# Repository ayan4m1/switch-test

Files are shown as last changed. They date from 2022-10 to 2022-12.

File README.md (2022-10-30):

# SwitchTest

An open-source mechanical keyswitch tester.

## Purpose

To provide a simple, reliable, and fast way to test a batch of keyswitches. You might want to perform batch testing after opening the switch housings in order to lubricate or swap springs. It can also be useful for those who buy and sell keyswitches, to quickly check them after receipt or before shipping.

## Bill of Materials

| Qty | Part | Notes |
| --- | --- | --- |
| 1 | [10k Ohm Resistor](https://www.amazon.com/dp/B072BL2VX1) | Through-hole, 1/4W is sufficient |
| 1 | [PS1240P02CT3](https://www.mouser.com/ProductDetail/810-PS1240P02CT3) | Piezo buzzer, 4kHz |
| 1 | [QT Py ESP32-S3](https://www.adafruit.com/product/5426) | |
| 1 | [0.96" SSD1306 OLED](https://www.amazon.com/gp/product/B0837DLWVH) | |
| 1 | [Kailh hotswap socket](https://divinikey.com/products/kailh-hot-swap-sockets) | |
| 4 | [M3 Standoffs](https://www.amazon.com/dp/B098XS4C3D) | 8-15mm length |
| 8 | M3 Screws | 5mm length |

You will also need a 3D printed [baseplate](./hardware/baseplate.stl).

Finally, PCBs are available from [this repo](./hardware/tester.brd).

## Schematic

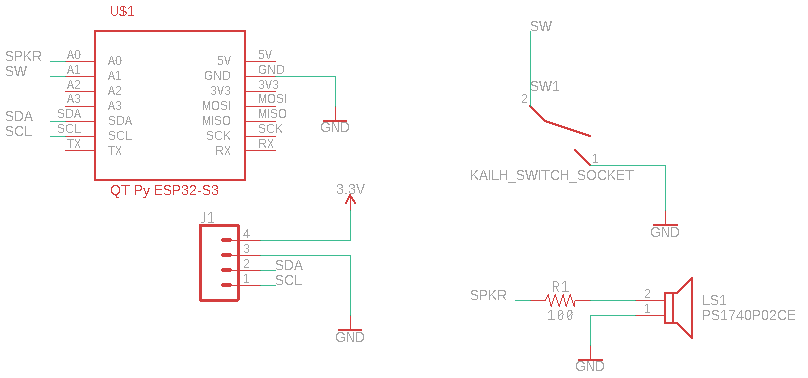
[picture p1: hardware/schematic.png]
Schematic showing microcontroller, display, switch, and speaker wiring


EAGLE schematics are available [here](./hardware/tester.sch).

## Assembly

1. Solder the resistor, OLED, and QT Py to the top of the board.
2. Solder the buzzer and switch socket to the bottom of the board.
3. Attach standoffs to the board.
4. Attach baseplate to the other end of the standoffs.

## Usage

1. Plug the board in to a USB-C cable.
2. Wait for the red LED.
3. Install a switch in the socket and press it. If the light turns green and the buzzer sounds, it is working. Otherwise, it is not.
4. Remove the switch and repeat step 3 for each switch.

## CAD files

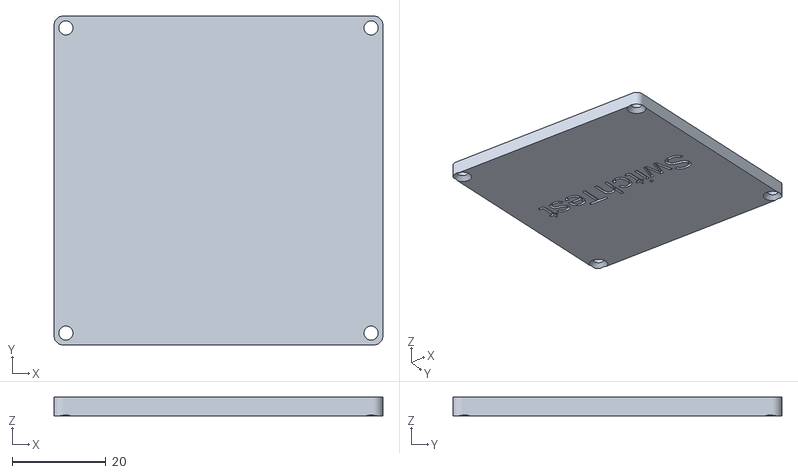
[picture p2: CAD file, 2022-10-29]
hardware/baseplate.stl
70.0 x 70.0 x 4.00

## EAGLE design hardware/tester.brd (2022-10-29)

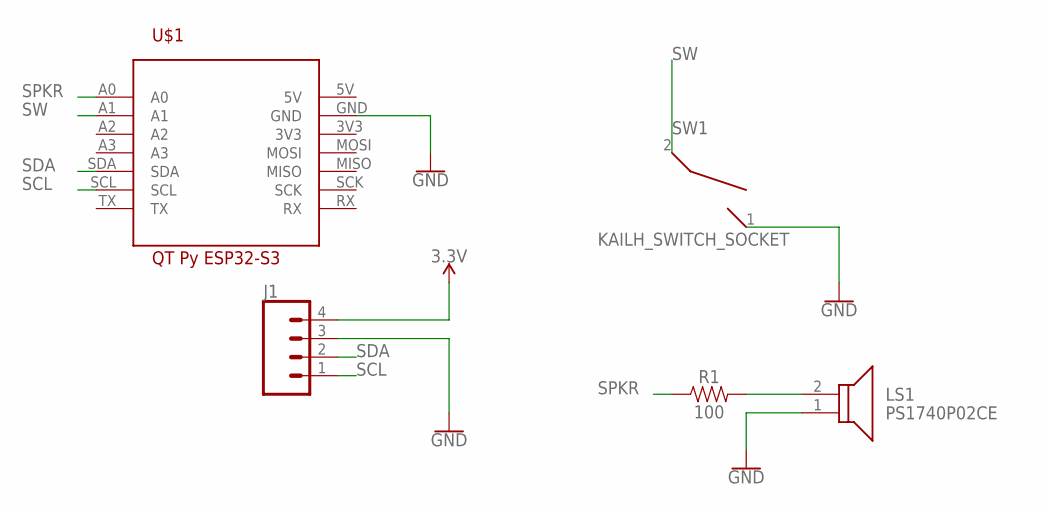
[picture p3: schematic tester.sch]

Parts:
J1: CONN_04; 1X04
LS1: PS1740P02CE
R1: 100; AXIAL-0.3
SW1: KAILH_SWITCH_SOCKET; SWITCH_SOCKET
U1: QTPY-ESP32-S3

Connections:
3.3V: J1.4
5V: U1.5V
GND: J1.3, LS1.1 (GND), SW1.1 (2), U1.GND
unnamed: LS1.2 (VCC), R1.P$2 (2)
SCL: J1.1, U1.SCL
SDA: J1.2, U1.SDA
SPKR: R1.P$1 (1), U1.A0
SW: SW1.2 (1), U1.A1

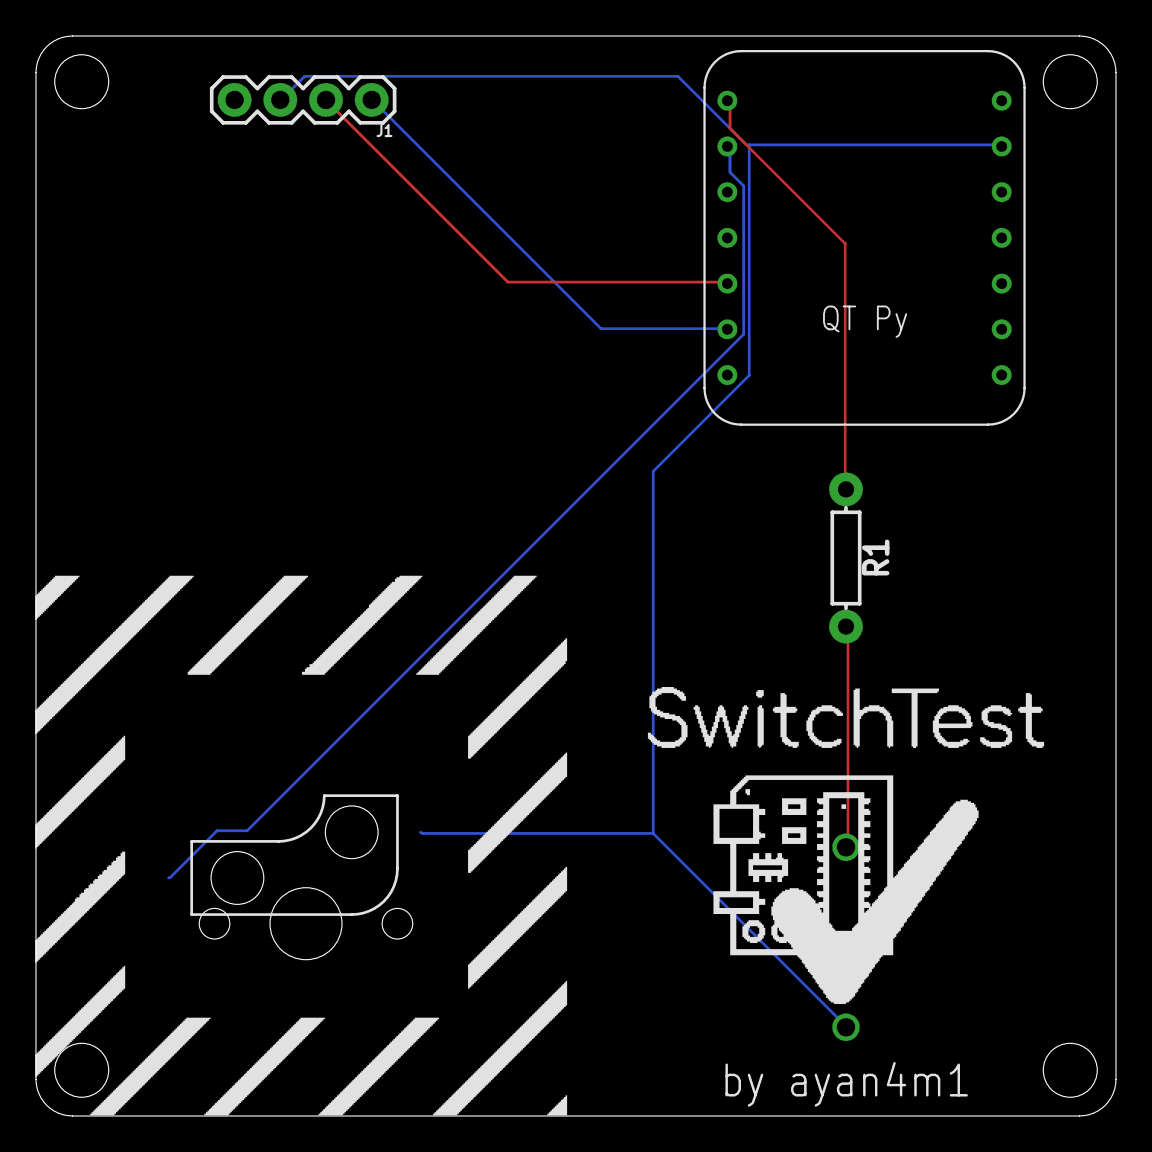
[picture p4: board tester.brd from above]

Board: 2 copper layers, 60.0 x 60.0 mm, 5 parts (1 on the bottom side), 6 nets.

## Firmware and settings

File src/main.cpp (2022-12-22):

#include <Arduino.h>
#include <FastLED.h>

#include <Buzzer.hpp>
#include <Display.hpp>
#include <htcw_button.hpp>

#define SWITCH_PIN 36

using namespace arduino;
using btn_t = button<SWITCH_PIN, 10, true>;

btn_t btn;
Buzzer buzzer = Buzzer();
Display display = Display();

void stateChange(const bool pressed, void* state) {
  display.setOk(pressed);
  if (pressed) {
    buzzer.playTone();
    display.incrementCount();
  } else {
    buzzer.stopTone();
  }
}

void setup() {
  display.init();

  btn.callback(stateChange);
  btn.initialize();

  buzzer.init();
  buzzer.playMelody();
}

void loop() {
  btn.update();

  EVERY_N_MILLIS(100) { display.update(); }
}

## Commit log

2022-10-28 add RGB LED functionality
2022-10-29 add README.md and hardware resources
    [baseplate.stl, tester.brd, tester.sch]
2022-10-30 toggle buzzer when pressing switch
    [main.cpp]
2022-10-30 change resistor value to eliminate squeal
2022-12-22 move to htcw_button, update pin assignments, target t-qt

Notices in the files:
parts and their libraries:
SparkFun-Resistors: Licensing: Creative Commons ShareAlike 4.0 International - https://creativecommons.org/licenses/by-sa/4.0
